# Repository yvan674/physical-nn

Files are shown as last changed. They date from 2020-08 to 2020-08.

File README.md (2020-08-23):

# Physical NN

This is meant to be as much a visualization of a simple artificial neural network as much as it is meant to be an art piece.

I previously did [some work](github.com/yvan674/minimal-mnist) experimenting with making a minimal neural network that could achieve a high accuracy on MNIST. When I visualized the results as a graph with the activation of each neuron being the color of each vertex, it looked quite nice visually so I decided to turn it into a physical visualization.

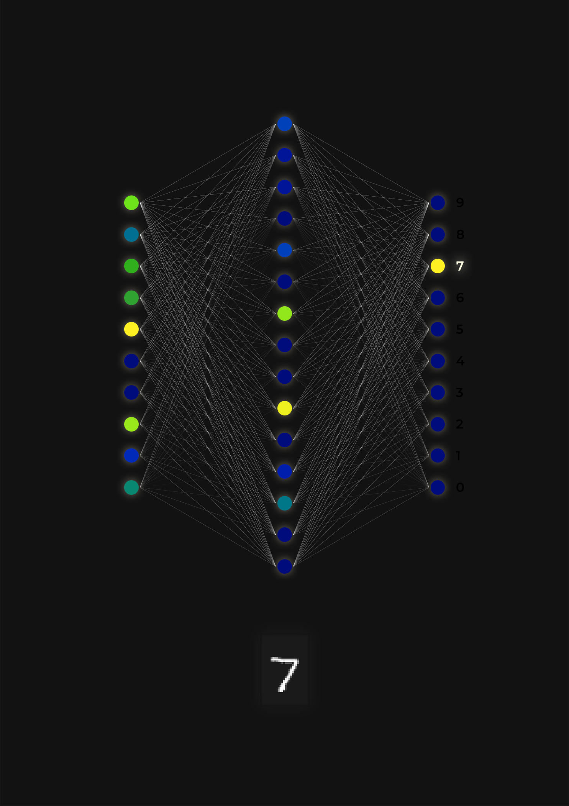
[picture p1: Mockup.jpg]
Mockup of the panel


The final product is a mounted acrylic panel with LEDs lighting up representing the respective activation level of each neuron.

## Acrylic Panel

The main part of the visualization is an acrylic panel with holes cut out for each neuron. Behind each of these holes is a small piece of white acrylic which diffuses the LEDs mounted behind them.

## LEDs and LCD

The visualization runs off of a Raspberry Pi Zero W with software from the [minimal-mnist](github.com/yvan674/minimal-mnist) repo. The LEDs are WS2812B LEDs and the LCD screen is a 3.5 inch Raspberry Pi compatible monitor.

## PCB

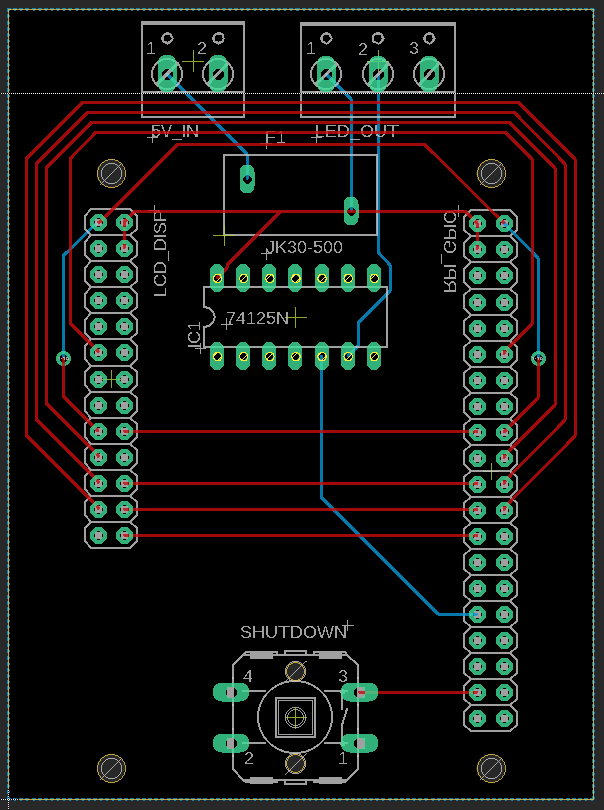
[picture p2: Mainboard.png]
Main PCB


To connect all of the components together, a custom PCB was designed that includes the power delivery and all required wiring between the components.

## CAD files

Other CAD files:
Acrylic Cuts.dwg

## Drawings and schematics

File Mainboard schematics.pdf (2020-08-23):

RPI Pins | LCD Pins

# GND ⁺³V³

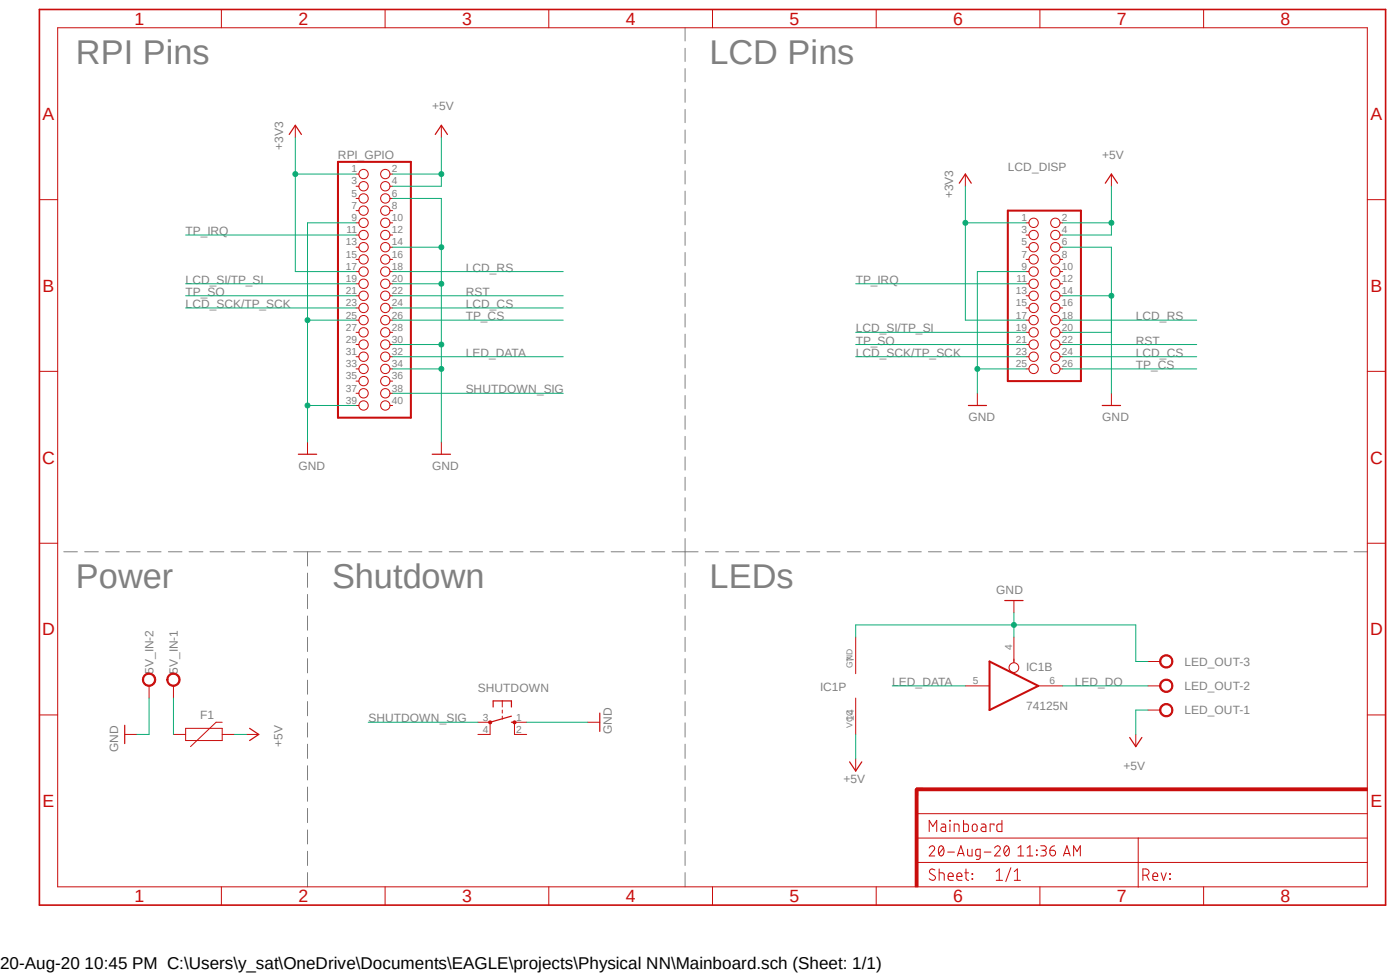
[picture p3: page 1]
Power; Shutdown; LEDs GND; GND; GND +5V; RPI_GPIO; 4 2 SHUTDOWN; LCD_DISP 5V_IN⁻²; LED_OUT-1; LED_OUT-2; LED_OUT-3; GND VCC 7 14; TP_IRQ; LCD_RS; LCD_SI/TP_SI; RST; LCD_SCK/TP_SCK; LCD_CS; SHUTDOWN_SIG; LED_DATA; LED_DO

GND ⁺³V³ GND

20-Aug-20 10:45 PM C:\Users\y_sat\OneDrive\Documents\EAGLE\projects\Physical NN\Mainboard.sch (Sheet: 1/1)

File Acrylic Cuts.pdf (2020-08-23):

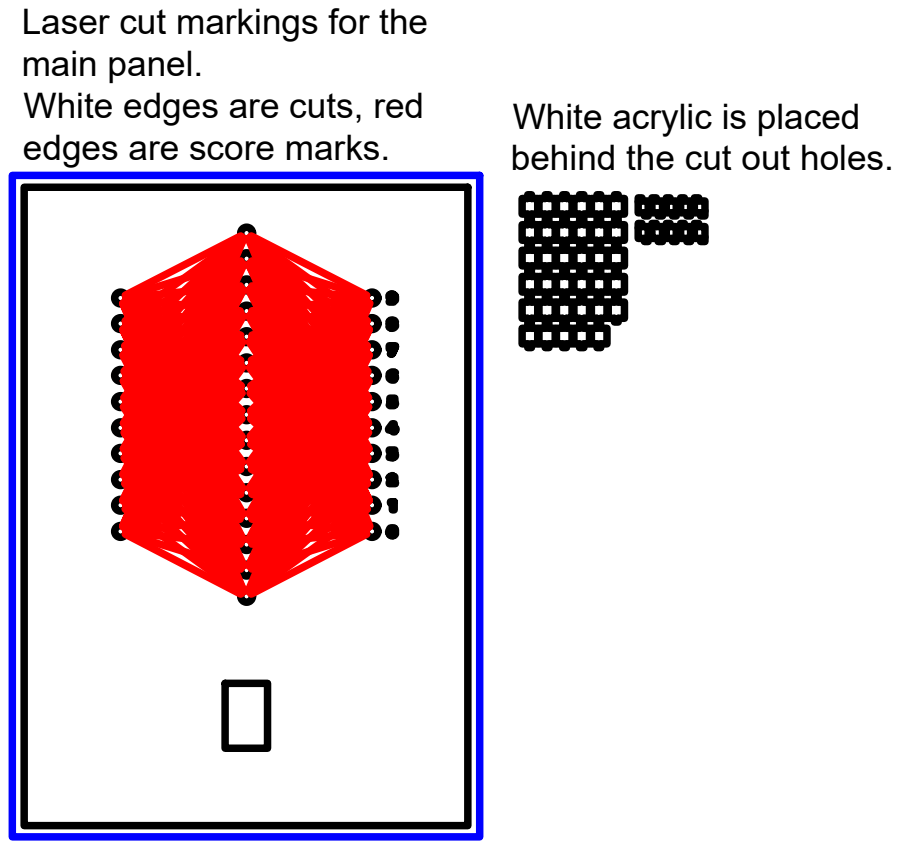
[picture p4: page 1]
edges are score marks.; White acrylic is placed

Laser cut markings for the main panel. White edges are cuts, red

behind the cut out holes.

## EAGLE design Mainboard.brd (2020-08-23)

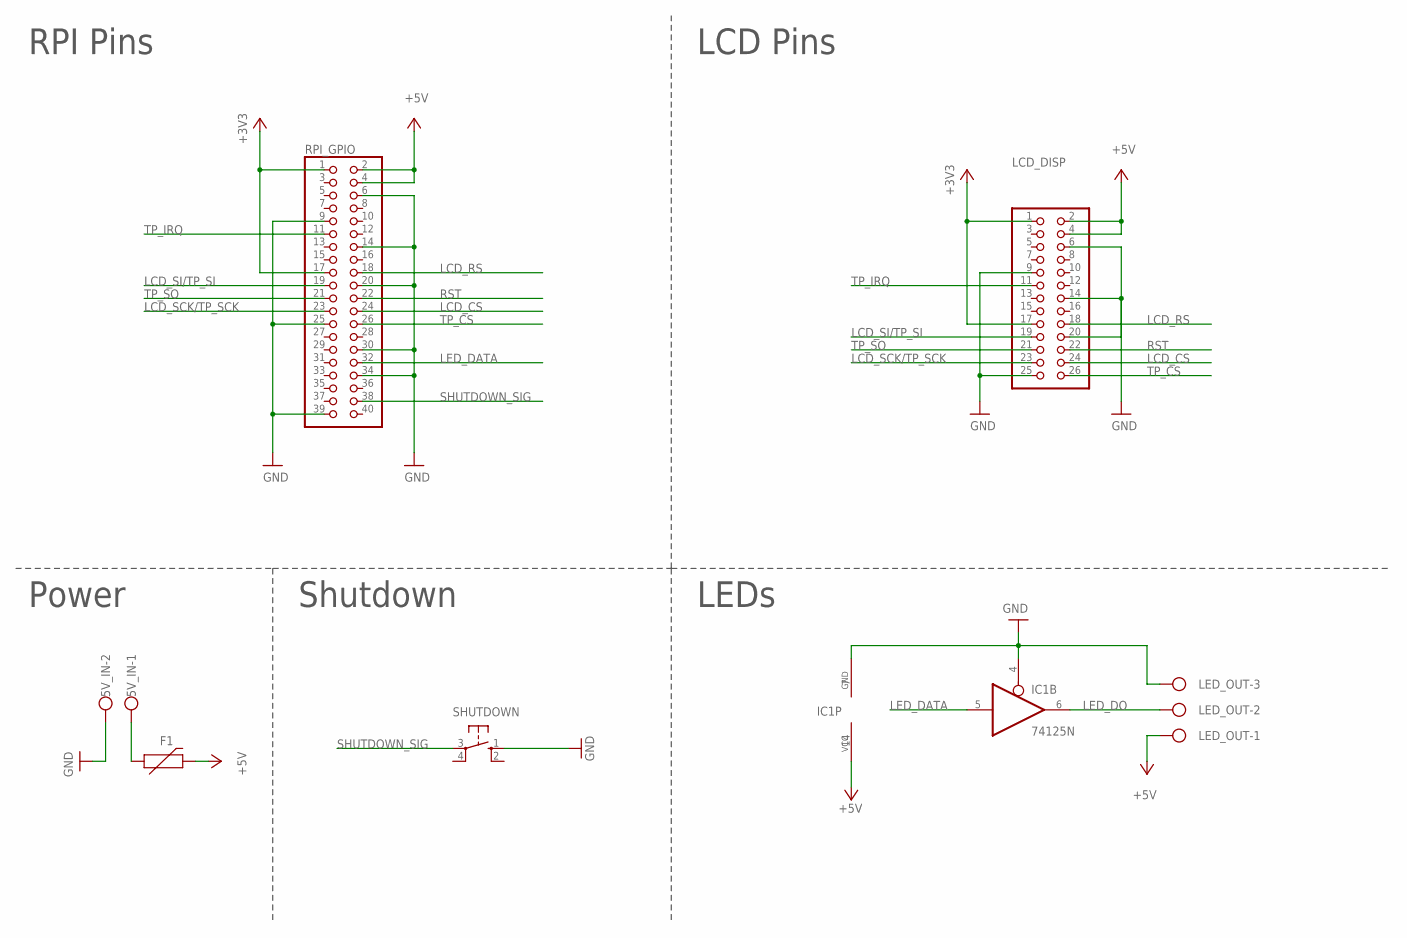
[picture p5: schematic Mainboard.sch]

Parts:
5V_IN: W237-102
F1: JK30-500
IC1: 74125N; DIL14
LCD_DISP: PINHD-2X13; 2X13
LED_OUT: W237-103
RPI_GPIO: PINHD-2X20; 2X20
SHUTDOWN: 40-XX; B3F-40XX

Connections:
+3V3: LCD_DISP.1, LCD_DISP.17, RPI_GPIO.1, RPI_GPIO.17
+5V: F1.P$2 (2), IC1.14 (VCC), LCD_DISP.2, LCD_DISP.4, LED_OUT.1, RPI_GPIO.2, RPI_GPIO.4
GND: 5V_IN.2, IC1.4 (OE), IC1.7 (GND), LCD_DISP.6, LCD_DISP.9, LCD_DISP.14, LCD_DISP.20, LCD_DISP.25, LED_OUT.3, RPI_GPIO.6, RPI_GPIO.9, RPI_GPIO.14, RPI_GPIO.20, RPI_GPIO.25, RPI_GPIO.30, RPI_GPIO.34, RPI_GPIO.39, SHUTDOWN.1 (S)
LCD_CS: LCD_DISP.24, RPI_GPIO.24
LCD_RS: LCD_DISP.18, RPI_GPIO.18
LCD_SCK/TP_SCK: LCD_DISP.23, RPI_GPIO.23
LCD_SI/TP_SI: LCD_DISP.19, RPI_GPIO.19
LED_DATA: IC1.5 (I), RPI_GPIO.32
LED_DO: IC1.6 (O), LED_OUT.2
unnamed: 5V_IN.1, F1.P$1 (1)
RST: LCD_DISP.22, RPI_GPIO.22
SHUTDOWN_SIG: RPI_GPIO.38, SHUTDOWN.3
TP_CS: LCD_DISP.26, RPI_GPIO.26
TP_IRQ: LCD_DISP.11, RPI_GPIO.11
TP_SO: LCD_DISP.21, RPI_GPIO.21

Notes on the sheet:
Power
Shutdown
RPI Pins
LCD Pins
LEDs

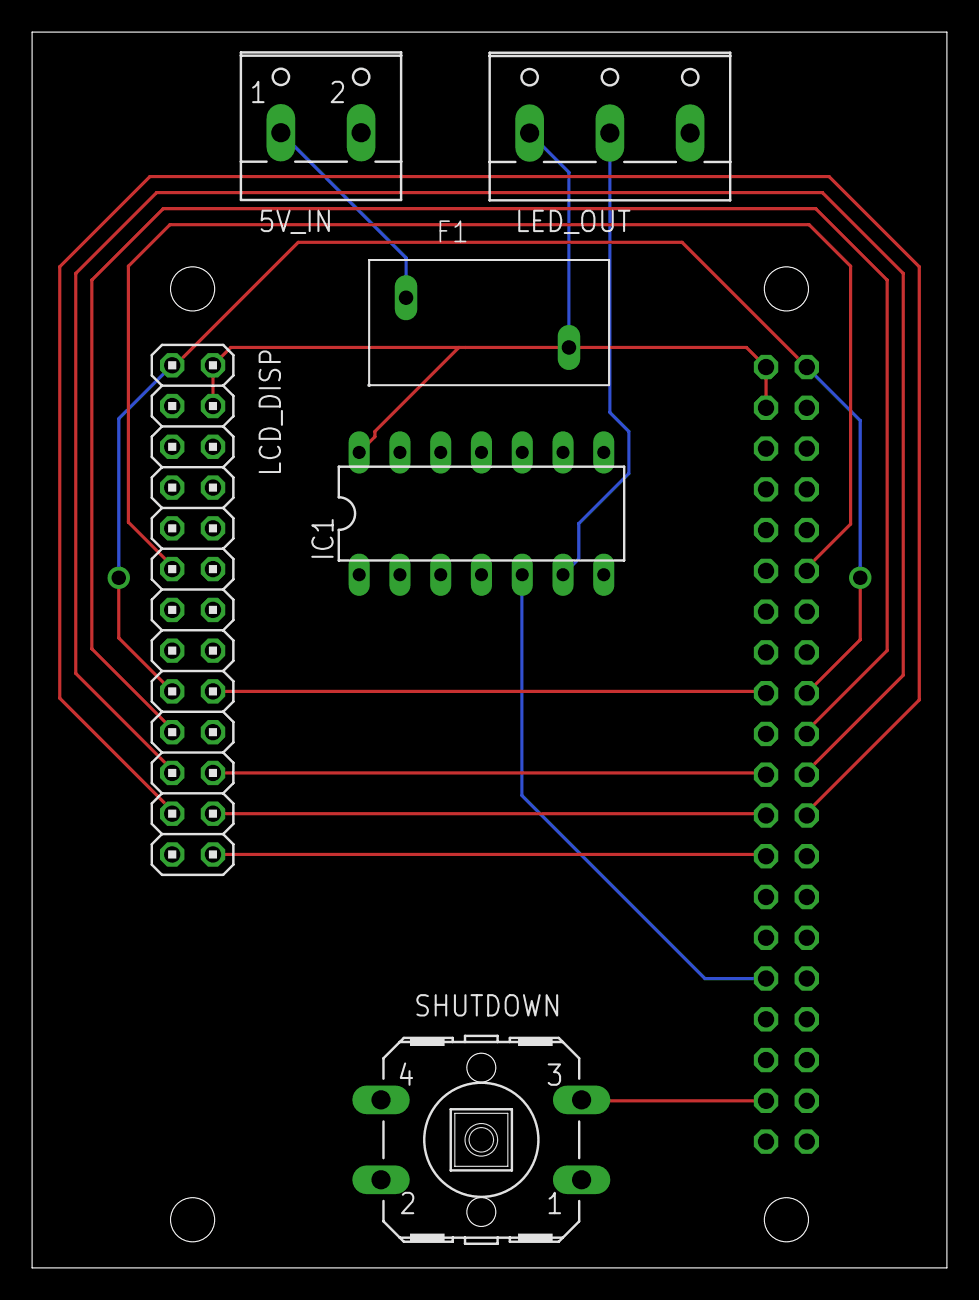
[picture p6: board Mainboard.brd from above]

Board: 2 copper layers, 57.0 x 77.0 mm, 7 parts (1 on the bottom side), 15 nets.

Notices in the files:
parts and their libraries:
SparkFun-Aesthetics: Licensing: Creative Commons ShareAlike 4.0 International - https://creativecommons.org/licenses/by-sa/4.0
